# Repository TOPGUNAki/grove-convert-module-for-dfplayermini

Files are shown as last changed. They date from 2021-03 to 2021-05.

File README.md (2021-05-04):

# Grove Convert Module for DFPlayer mini

DFPlayer mini Grove変換モジュール



## 特長
DFPlayer miniを差し込むことにより、ホストマイコンからGroveコネクタ経由でDFPlayer miniを制御できます。  
基板のスルーホールにスピーカーを直接つないだり、φ3.5mmステレオジャック経由で外部のスピーカーと接続できます。  
実装したスピーカーの音量が足りないなぁ…というときに、外部スピーカー接続に変更して音量を上げるといったこともできます。  
また、通信確認用のLEDも実装しています。

## デモ
### micro:bit




[micro:bit プログラム例](https://makecode.microbit.org/_3q2T52P9qFmp)

## 注意点
DFPlayer miniのピンソケットが若干狭いので、少し広げて接続してください。



## スペック
 - 基板サイズ(コネクタ込): 40 × 24 × 12mm  
 - VCC電圧：3.3V or 5V
 - TX/RXピン信号電圧：3.3V
 - ジャック端子：ステレオミニ φ3.5mm

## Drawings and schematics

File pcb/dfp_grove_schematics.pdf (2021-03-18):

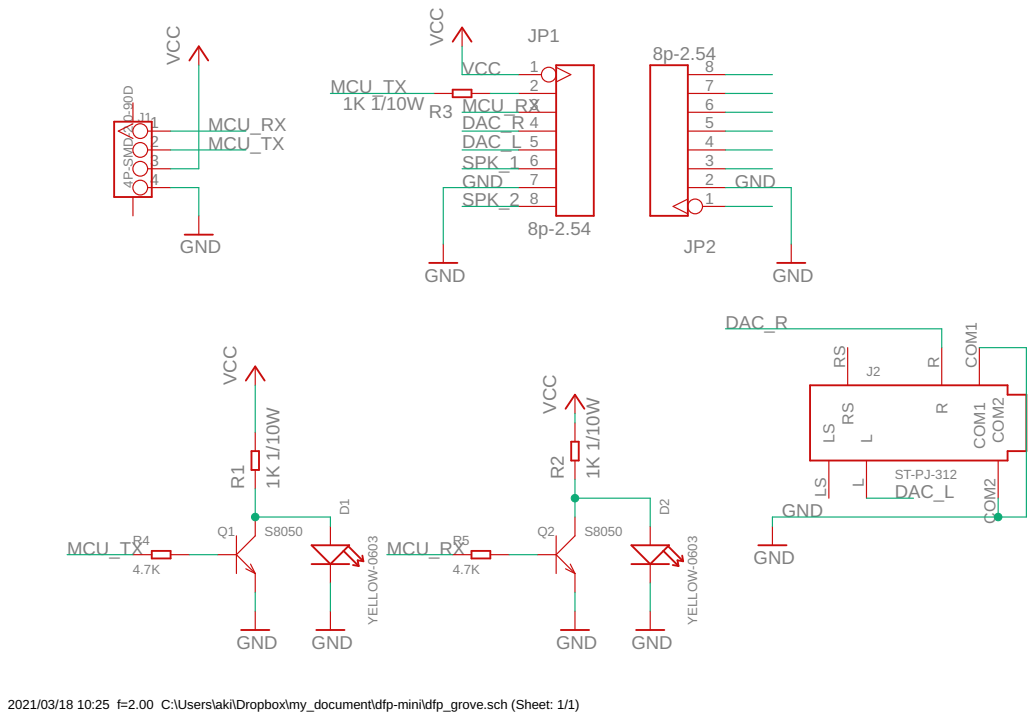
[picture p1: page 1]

2021/03/18 10:25 f=2.00 C:\Users\aki\Dropbox\my_document\dfp-mini\dfp_grove.sch (Sheet: 1/1)

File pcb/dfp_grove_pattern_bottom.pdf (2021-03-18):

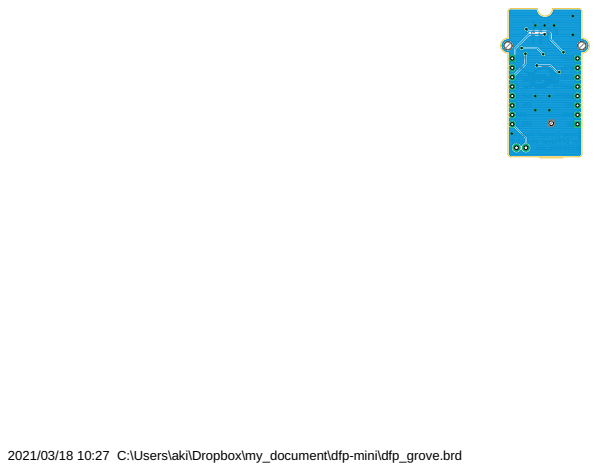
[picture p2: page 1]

2021/03/18 10:27 C:\Users\aki\Dropbox\my_document\dfp-mini\dfp_grove.brd

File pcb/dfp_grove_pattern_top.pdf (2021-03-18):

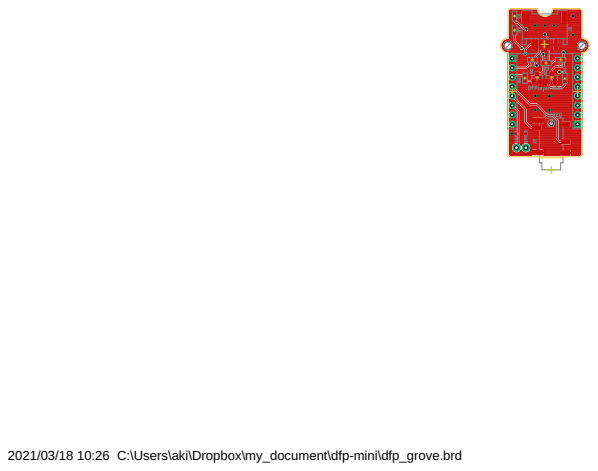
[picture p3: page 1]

2021/03/18 10:26 C:\Users\aki\Dropbox\my_document\dfp-mini\dfp_grove.brd

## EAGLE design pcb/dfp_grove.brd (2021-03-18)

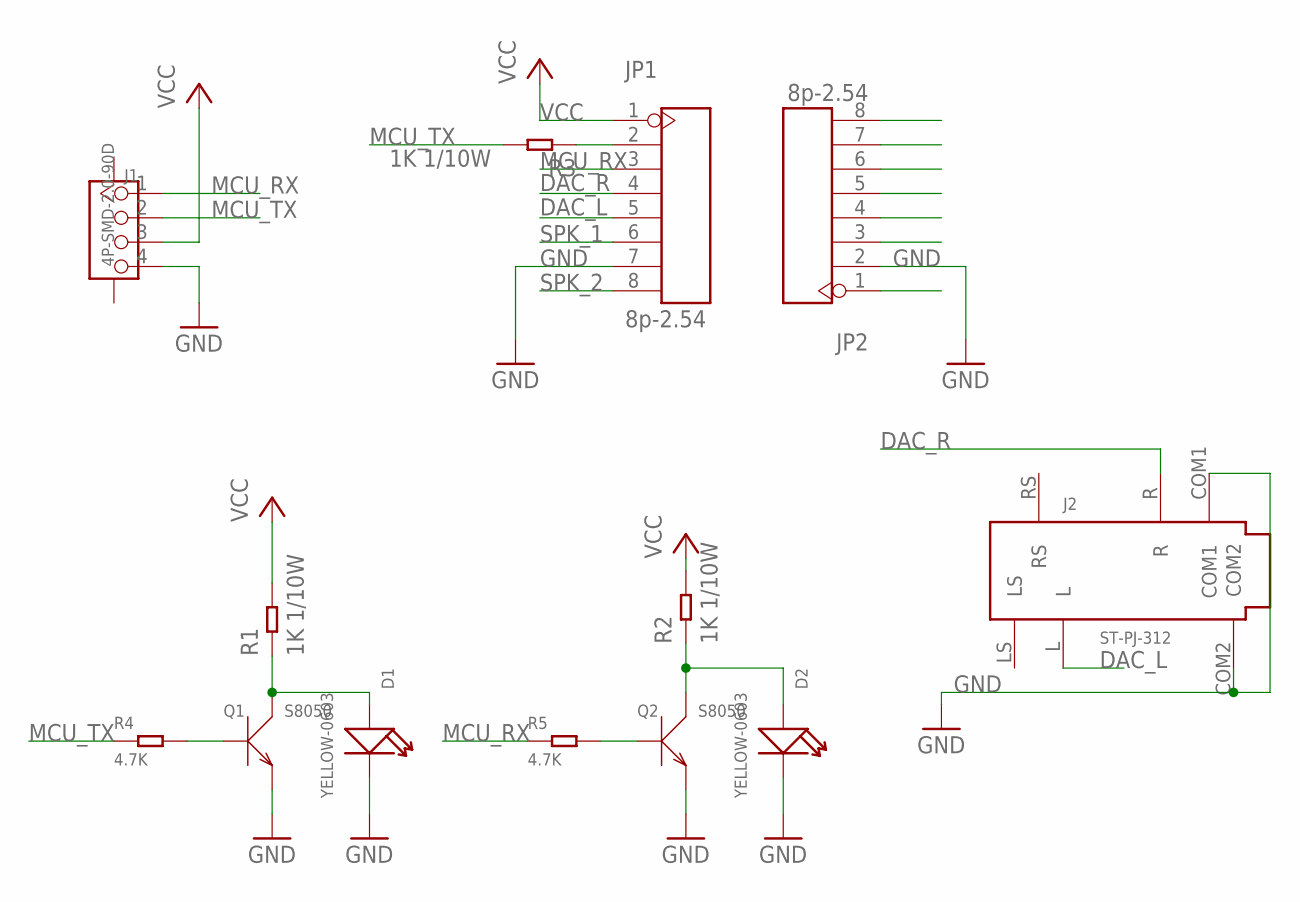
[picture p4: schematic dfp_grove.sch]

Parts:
D1, D2: YELLOW-0603; LED-0603
J1: 4P-SMD-2.0-90D; HW4-SMD-2.0-90D
J2: ST-PJ-312; AUDIO6P-SMD-3.5-14.0X6.4X5.0MM
JP1, JP2: 8p-2.54; H8-2.54
Q1, Q2: S8050; SOT-23
R1, R2, R3: 1K 1/10W; R0603
R4, R5: 4.7K; R0603

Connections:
DAC_L: J2.L, JP1.5
DAC_R: J2.R, JP1.4
GND: D1.-, D2.-, J1.4, J2.COM1, J2.COM2, JP1.7, JP2.2, Q1.2 (E), Q2.2 (E)
MCU_RX: J1.1, JP1.3, R5.1
MCU_TX: J1.2, R3.2, R4.1
unnamed: D2.+, Q2.3 (C), R2.1
unnamed: Q2.1 (B), R5.2
unnamed: Q1.1 (B), R4.2
unnamed: D1.+, Q1.3 (C), R1.1
RX: JP1.2, R3.1
SPK_1: JP1.6
SPK_2: JP1.8
VCC: J1.3, JP1.1, R1.2, R2.2

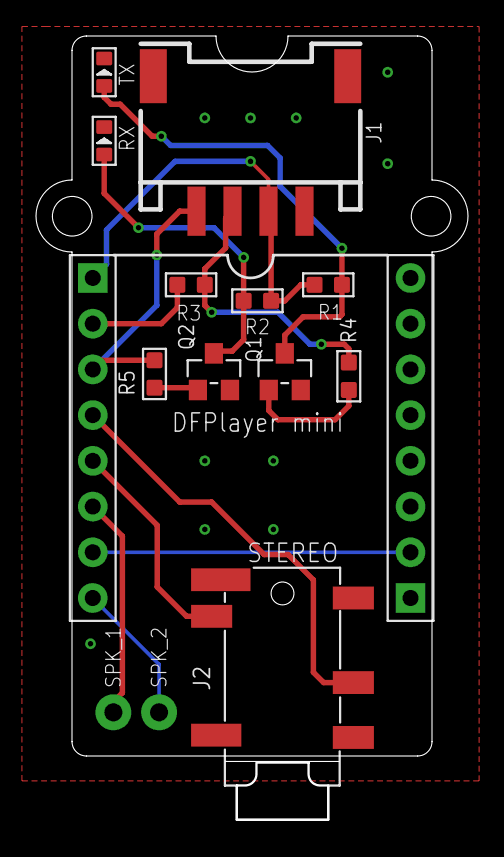
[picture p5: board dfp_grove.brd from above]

Board: 2 copper layers, 24.0 x 43.5 mm, 13 parts (0 on the bottom side), 11 nets.

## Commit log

2021-03-18 first commit. this is v1.0.0
    [dfp_grove.brd, dfp_grove.sch]
2021-03-18 Readmeを作成
2021-03-18 pcbフォルダに基板関連データを移動
    [dfp_grove.brd, dfp_grove.sch]
2021-03-18 add pdf of pattern and schematics
2021-03-18 説明を追加
